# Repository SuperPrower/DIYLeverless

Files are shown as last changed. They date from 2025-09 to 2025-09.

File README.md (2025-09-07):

# SuperPrower's notes on DIY Leverless controllers

This repository contains my notes, pictures, and CAD files of the leverless controllers I have built or attempted to build.

Rather than being a blueprint for a projects, it should be used as a reference, inspiration or a list of mistakes to avoid. DIY mindset required.

Notes range from my philosophy when approaching something to my experience and advice based on it.

Repository structure:
- `flatbox`: contains the notes on my first controller, based on the [flatbox](https://github.com/jfedor2/flatbox) rev4 - TBA.
- `woodbox`: my most recent controller, built out of generic wooden box for storage.

The "Homework" sections contain mistakes I've made and things I would do differently in the future. If one is present, please read it if you're trying to replicate or be inspired by some of the ideas.

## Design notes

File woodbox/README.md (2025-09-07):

# Matchstick Box (aka Woodbox)

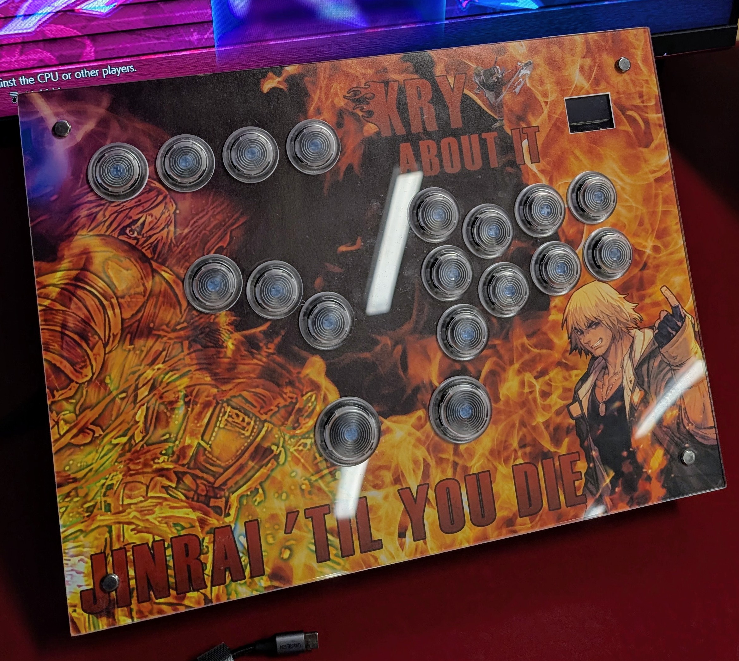
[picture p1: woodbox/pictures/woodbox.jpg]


The goal of the project was to make a controller that would be more comfortable for people with wider shoulders through split layout (movement buttons and attack buttons separated). Additionally, it was supposed to prevent Ulnar Deviation / wrist angling by slightly tilting each button block inwards. Bigger size also helps with more comfort when placed on the knees, which is something I would typically have to do at locals.

The initial sketches for button layouts were fitting roughly on the A4 sheet of paper. As such, I opted to purchase a hobby wooden box that could fit an A4 sheet inside.

I used a laser cutter at my local hackspace to cut the lid of the box and a sheet of acrylic to go on top of it.

## Files in this directory
Notes:
- [DESIGN.md](DESIGN.md) - notes on design of the controller
- [MAKING.md](MAKING.md) - notes on actually building the controller
- [WIRING.md](WIRING.md) - notes on installing the buttons and wiring them

Other files:
- [ButtonLayout.FCStd](ButtonLayout.FCStd) - the layout of the buttons and cutting layout for the case and acrylic plate, see [DESIGN.md](DESIGN.md) for notes.
- [USBPortMountPlate.FCStd](USBPortMountPlate.FCStd) - extra detail to help mount the USB port extender to the case, see [DESIGN.md](DESIGN.md) for notes.

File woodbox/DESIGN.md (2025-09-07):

# Design Notes

## Button layout
I'm not sure why the layout where movement and attack buttons are close together is so popular. I guess HitBox really wants to show you all the cool things you can do by pressing one movement button and one attack button with the same hand. However, in practice, I've never personally seen anyone actually do that.

I've started my design by basing it on some of the artwork layouts available for controllers. I had to adjust the spacing between the buttons to accommodate for the lip. In the end, I have probably overcompensated, but it works for me - you could probably go with smaller spacing.

Afterwards, I added the additional buttons, moved the button blocks further away from each other and rotated them inwards.

The button I've used have tabs on sides, and were intended to be used with a panel thinner, than the combined width of the plywood top and acrylic sheet. That's why I've added small cutouts to the sides of the holes when cutting plywood. I've been inspired by this [reddit post](https://old.reddit.com/r/fightsticks/comments/1auxf83/custom_leverless_controller_panel_design/).

Here is how one of the final iterations of the layout looked like (prepared for manual drilling, before I decided to use a laser cutter):

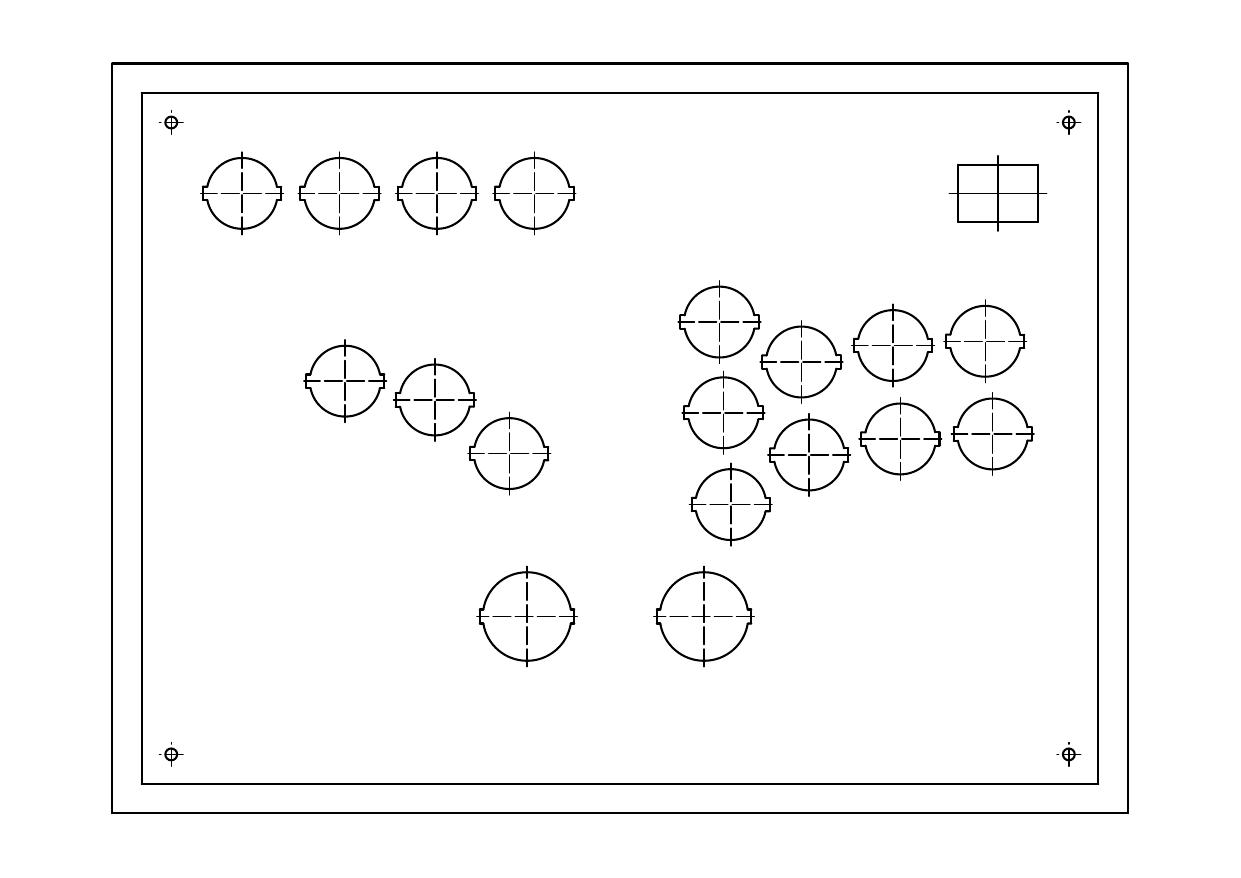
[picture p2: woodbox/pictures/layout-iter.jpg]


### Homework
- The layout I based mine on has LK and LP buttons (in SF6 notation) almost perfectly one on top of another. I found that not as nice, because I like to press those two buttons together with my index and middle fingers. I would re-design the layout based on the flatbox, which has the bottom row shifted slightly to the left, maybe even moving it more to the left slightly.
- I believe I overdid the split between the button blocks. I would go with a gap maybe 5 mm smaller.
- I rotated each button block inwards by 12.5 degrees around the larger 30mm buttons. However, I think it is very slightly too much. Next time I would go with ~10 degrees, especially when coupled together with the previous two changes.
- I'm not very familiar with the CAD software and FreeCAD in general. As such, after making the initial layout as a sketch, I made a copy of it and rotated each button block separately, losing most of my constraints and having to re-do them manually. Please find a better way to do that.
- Similarly, I've added the notches for buttons as rectangles and then merged them in the Laser Cutter software. Trying to merge them in the FreeCAD just caused me to lose constraints, which I didn't want.

## USB mount plate
The box I've purchased didn't have enough height in the wall to mount a Neutrik-style USB port. As such, I've opted to purchase a flatter USB Type C panel mounted extender. However, I didn't realize that you are intended to screw a thin plate on top of it, not screw it to something behind it. As such, I quickly designed a plate with 2 screw holes to mount the USB extender to it, 2 screw holes to mount it to the box, and a hole for the USB cable.

Unfortunately, I placed the holes through which the plate would be mounted to the case too close to the other holes. Because I was adding furniture threaded inserts to the case (think typical brass threaded insert, but for wood), they ended up not having enough clearance and not being safely covered by the wood from all sides:

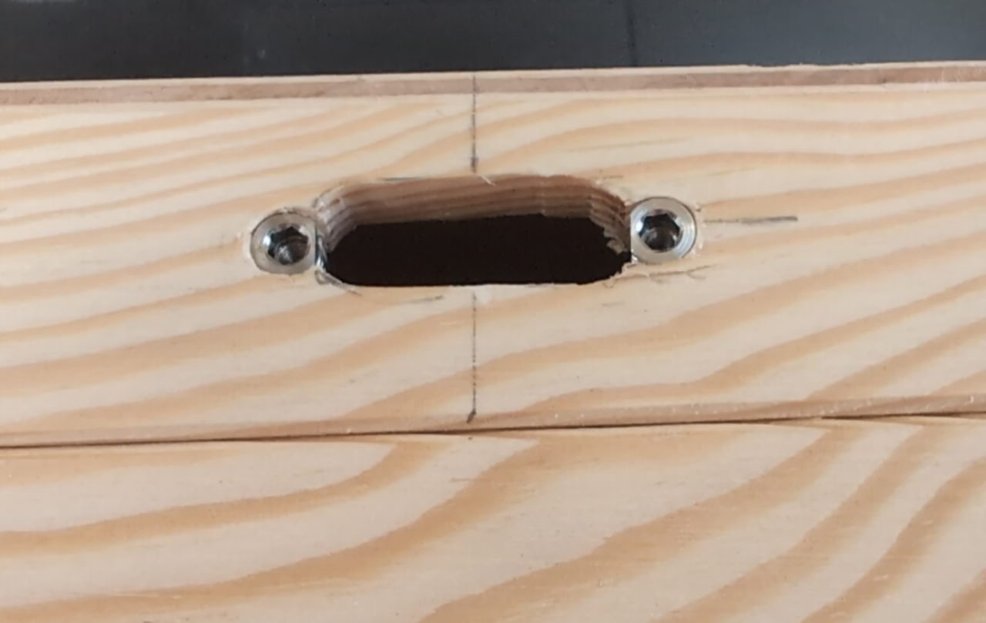
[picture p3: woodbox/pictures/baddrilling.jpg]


A lot of glue and wood filler eventually solved the problem, but I'm afraid to tighten the screws now. However, it works, and in theory I can disassemble the installation to replace the extender cable:

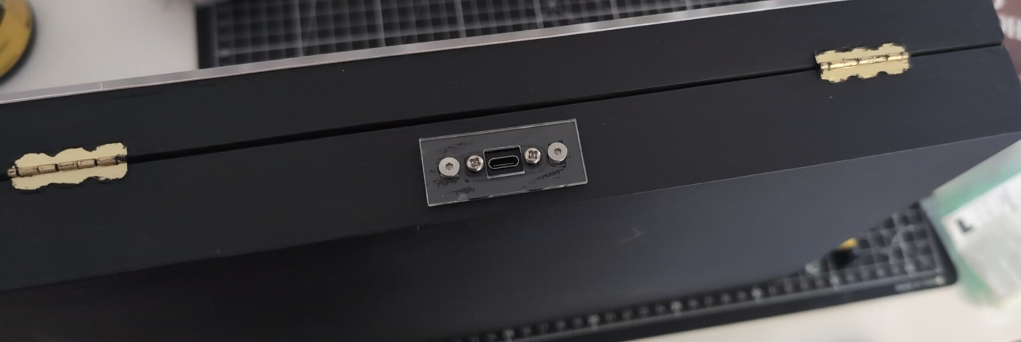
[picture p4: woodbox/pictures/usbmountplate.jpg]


### Homework
* Use a better USB extender - I believe Punk Workshop sells a similar one, but with screw holes being further out from the body of the USB port, or use a Neutrik-style panel mounted USB port.

## Display

I've added a small cutout to fit a small OLED. However, I didn't plan for mounting it - on the layout above, you seen that I only planned a hole for the display itself. Also, I had to manually sand out a small notch for the ribbon cable on the OLED. As such, it stays in place with friction between the edges of the display and the wood, and some tape.

### Homework
* Find a good way to mount a display. If the display is not touching the surface, I think it is possible to hide the bottom part of the glass that doesn't show anything, removing the need for a cable notch altogether.

## Artwork
I have exported the laser cutter layout for the acrylic sheet as svg and used it to design an artwork around it. I'm not sharing the art to avoid violating copyright, but I've used CC images of fire, various filters and layer blending modes in GIMP editor, and the following images:

- https://www.pixiv.net/en/artworks/101323675
- https://x.com/click_burgundy/status/1570615560433729536

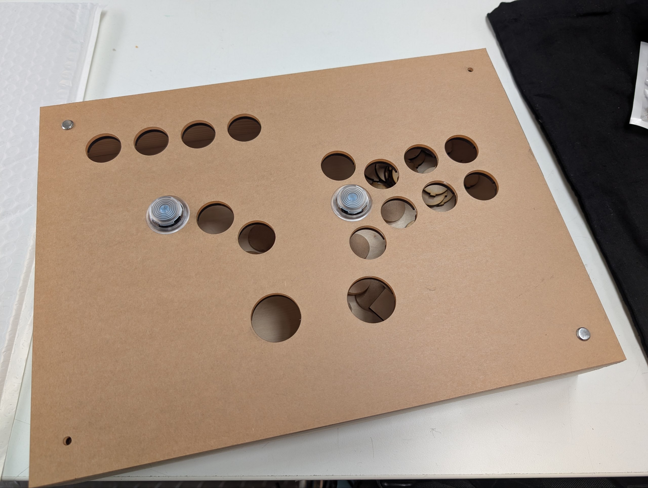
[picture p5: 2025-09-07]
woodbox/pictures/lasercut2.jpg

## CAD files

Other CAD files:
woodbox/ButtonLayout.FCStd
woodbox/USBPortMountPlate.FCStd

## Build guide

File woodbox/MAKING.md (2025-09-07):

# Notes on building the controller

## Making the holes for the buttons
I was initially planning to use a drill to make holes in the top lid of the box, but kind people at the hackspace suggested trying to use a laser cutter. The lid of the box is made out of thin plywood - 3-4mm thick - and the lid itself was short enough to fit under the moving head of the laser cutter.

I was very pleased with how it turned out. I plan to design my future controller around the laser cutter.

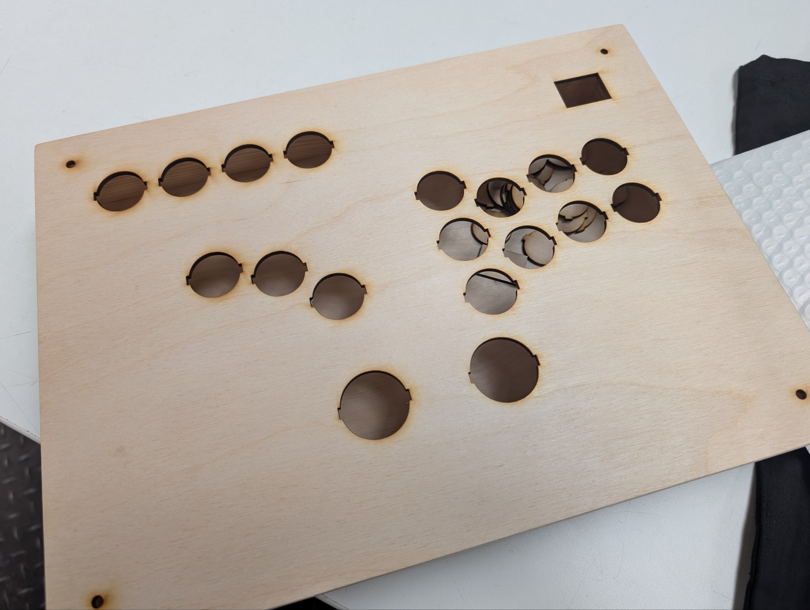
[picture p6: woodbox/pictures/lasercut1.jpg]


### Homework
- None! Laser cutter rules.

## Making the hole for the USB extender

For the USB extender, I drilled a round hole of the diameter matching the height of the USB extender, and then widened it using a Dremel-like tool and files. I don't recommend that approach, as the hole was uneven, I had to file it, fill it with the wood filler, and sand it, and after painting I had to slightly sand the casing of the USB extender.

To mount the USB Extender, I had to use a mounting plate - see DESIGN.md for explanation. As I wrote there, I miscalculated the width of the threaded inserts, and ended up with suboptimal mounting.

### Homework
- Find a better approach to making a non-round hole
- Plan for more space for the threaded inserts.

## Painting

My painting experience is limited by painting small plastic dudes. As such, I didn't know where to start with painting a box made out of pine and plywood. A WikiHow article suggested using a shellac-based primer, but I couldn't really find one in my closest hardware store. I also tried using some advice from an LLM, but in retrospect it was clearly making shit up based on the techniques used for painting small plastic dudes or painting outdoor furniture. I ended up buying a can of 2-in-1 acrylic paint & primer, rated for outdoor and indoor use, supposedly also fitting for use with the toys. I think that was an OK decision, though I was later criticized for painting a relatively small DIY project "like a wood fence".

First layers looked very promising:

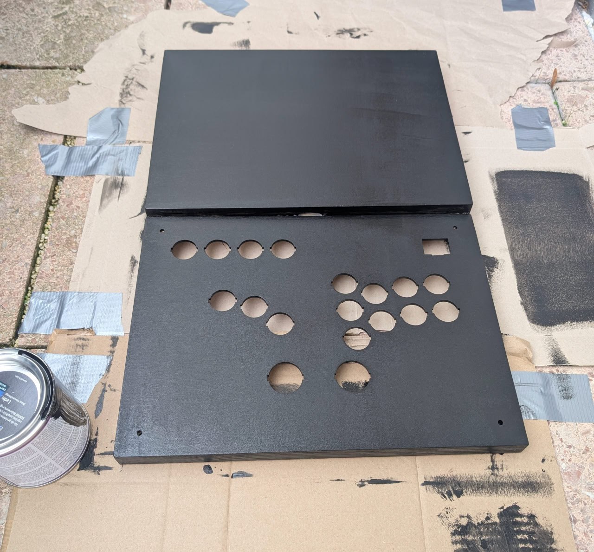
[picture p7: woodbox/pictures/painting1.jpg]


However, as I went on, it was clear that I was doing something wrong. Not only having to wait for ~24 hours between painting sessions seemed excessive, especially given that I had to paint my box inside and outside and on the sides, but soon enough paint started to look much worse:

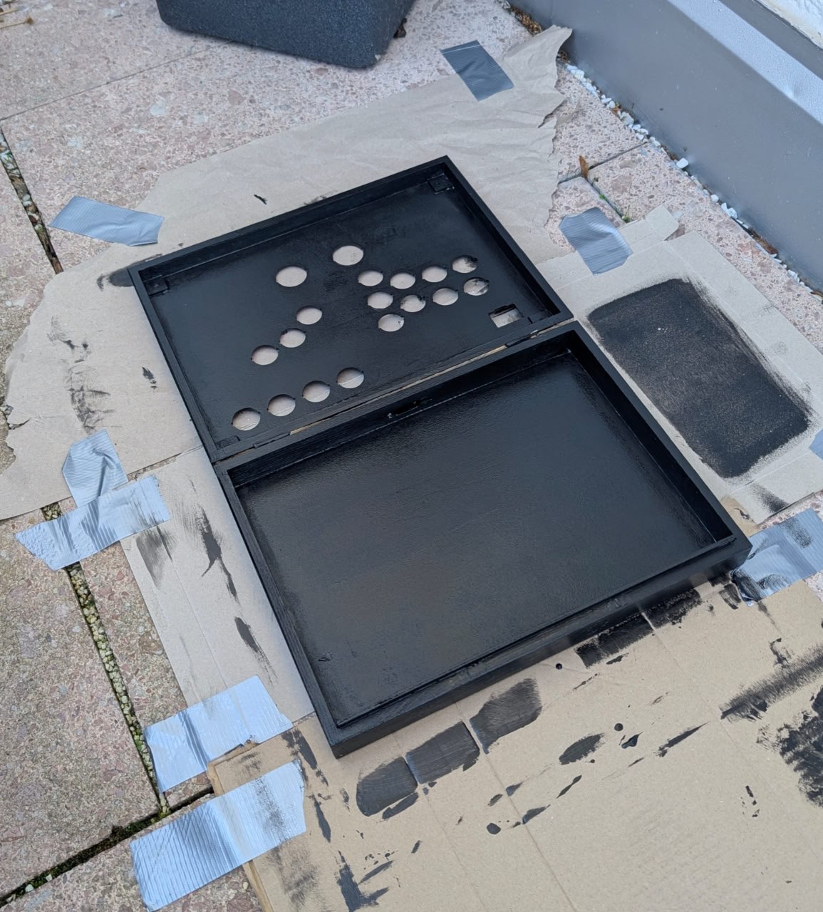
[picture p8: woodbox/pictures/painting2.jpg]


It was at that point that I realized that not only did I not stir my paint, but also that I was probably using a roller incorrectly. Oh well - after approximately two coats from each side and then some after sanding down blobs of paint, I had to call it "good enough".

Thankfully, after applying a clear coat from a spray can, the texture and appearance actually improved quite a bit. I really like the satin look of the clear coat, and would go for it again:

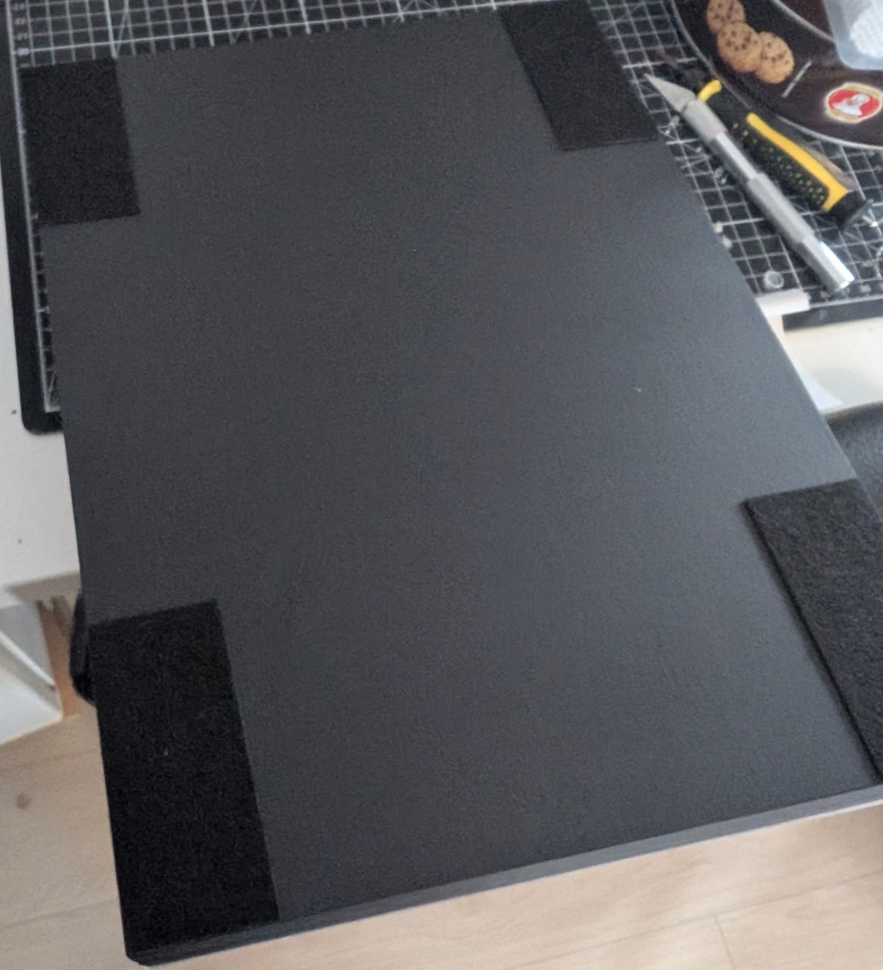
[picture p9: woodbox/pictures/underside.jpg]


### Homework
- When using a wooden box for case, some better painting approach should be used. Either just spraying it with the paint instead of using more generic outside paint, or some other painting approach.
- Don't forget to stir your paint first!
- The paint was so thick, that it completely glued the masking tape that I have applied to various metal parts to the box. It didn't help that because I had to open the box to paint the larger surfaces and close it to paint the sides, the masking tape didn't work as well in some places, like hinges - you can still see some paint on them, even though I did my best to scrape it or rub it off with isopropyl alcohol. In general, aim for a better masking job.

## Miscellaneous stuff

I also added some furniture gliders made from felt (see the picture above). Normally people add non-slip rubber feet to their controllers, but I haven't felt the need to - I just wanted to protect my controller from the surfaces (or vice versa), and make it a bit more comfortable to play with when wearing shorter clothing. I think it worked well enough.

The artwork was printed at the copy shop. Next time, I would go for a glossier and thicker paper to make it easier to cut holes for buttons.

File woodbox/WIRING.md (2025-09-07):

# Notes on wiring the controller

## Buttons

I've purchased a set of Punk Workshop buttons on AliExpress. I quite enjoyed having keyboard switches in my flatbox, and as such, chose the buttons which used them. The listing seems to be gone from the reseller, but they are listed as "PWS v1" on Punk Workshop webstore - albeit with button caps seemingly being deeper in the button case.

These buttons use 2.8mm terminals. I've bought a set of male and female 2.8mm terminals with covers for wiring, but I didn't enjoy using them - they are very hard to insert and remove - I would look for something more akin to what is used in the Brook harness.

## LEDs

When I received my buttons, I've noticed that the switches inside of them (Cherry MX Blue) had a small place for an LED in them. Turns out that those switches perfectly fit a 3mm LED. The button housing didn't have any holes for the diode legs, but if I bent the legs at the bottom of the switch, I could have them sticking out from the side of the button:

TODO picture of switch and LED

TODO picture of button with LED legs visible

As such, I made a decision to add an LED to the buttons. GP2040-CE has its own support for addressable LEDs, but it would be difficult to fit one into the switch, so I decided to make them activate on the button press.

I have found that GP2040-CE configures its buttons such that when pressed, they pull the pin down to the ground. With that knowledge, I was able to connect the anode of the LED to the VCC pin, and the cathode to the GPIO pin. This way, when the button is pressed, the circuit will close, and an LED will light up, but if LED dies, the button won't stop working.

TODO schematic of LED

### Small note on LEDs
The Cherry MX switches (non-RGB version) fit 3mm LEDs, however I've discovered that depending on the color, some LEDs' skirts needed to be slightly sanded down to fit into the switch, while others fit perfectly or even slightly loose. Your mileage may vary, but in my experience, yellow and red LEDs fit snugly, green LEDs are a bit loose, and blue and white LEDs needed to be sanded down. Other switches may expect different size of LEDs, for example 1.8mm.

### Homework
- I wanted to make it so I don't need to de-solder anything to remove the button. To achieve that, I've soldered 2.8mm terminals, same ones used by the buttons, to the legs of LEDs. I've also soldered a resistor to the LED instead of to the cable going to it. However, this proved to be a bad decision, because all of it takes too much space and looks really messy at the end:
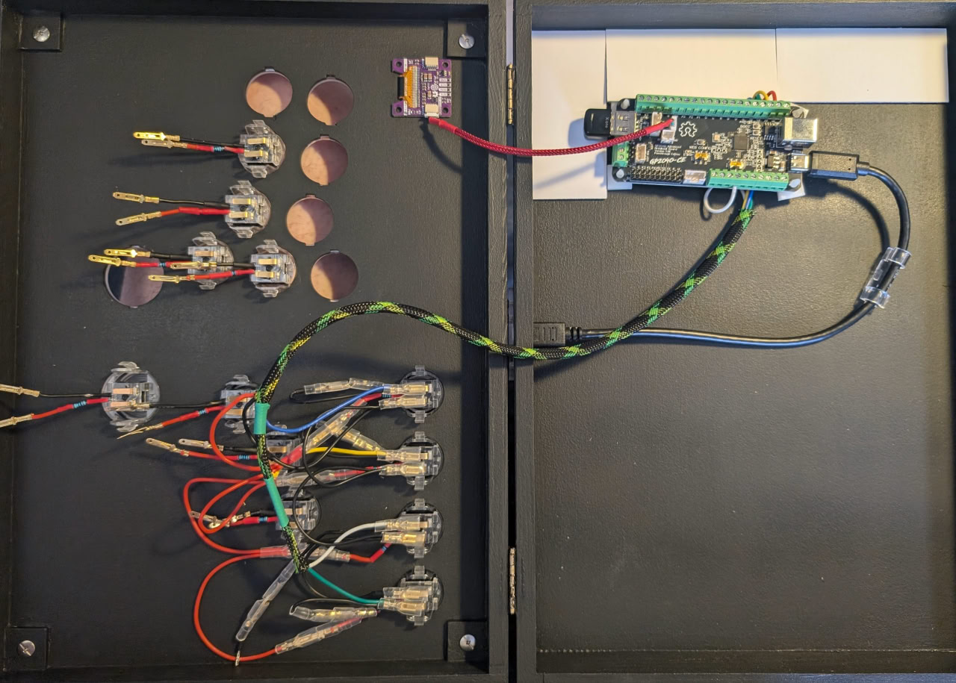
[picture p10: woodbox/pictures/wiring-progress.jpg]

- Next time, I would probably look for some sort of connection which would fit the legs of LEDs and hold them firmly, similar to how hot swap sockets for keyboard switches work.
- Either because the VCC pin on the board is 5V and the logic pins are pulled up to 3.3V or for some other reason, some LEDs, namely reds and to a lesser extent yellows, can be faintly seen glowing when not pressed. That's probably not great for their longevity.

## Component placement

I've made a decision to have the GP2040 board at the bottom part of my case, with cables going to the top part. This was done partly because the pre-crimped JST SH 1.0mm (a.k.a. QWIIC) cables I had that I used to connect an OLED were really short, and because the USB extender was mounted in the bottom part. That worked out in the end, but next time I would try to have all of the components mounted on the same surface.

Also, I didn't plan a proper mounting for OLED. I couldn't use the same stands that the board uses, since they would cover the screen. For now, it stays put with friction and some tape.

### Homework
- Plan for the board to be on the same surface with the buttons.
- Plan better mounting for the OLED.

## Wiring

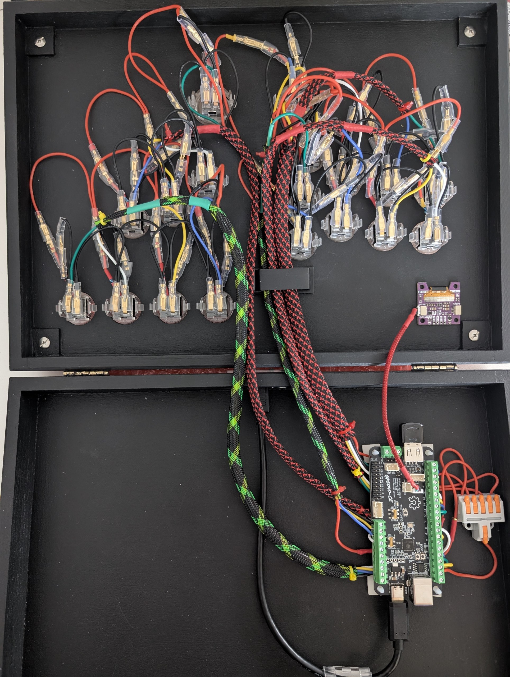
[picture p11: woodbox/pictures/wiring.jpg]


Although I've bought a pre-made cable harness for leverless controllers, I didn't want to use it since the pin grouping wasn't working for me, and I was worried that the 20 pin connector would make the board too tall. I ended up making my own cable harnesses, intended to be connected to the screw terminals on the GP2040 board.

TODO picture of harness

I've used 22 AWG wires. I think they are a bit on the thicker side, especially when compared to the typical wiring job, but I think they worked well with the 2.8mm terminals that I've used, though I couldn't fit 2 cables together inside the terminal for crimping without fully removing the isolation. Next time, I would probably go with something slightly smaller, but definitely thicker than 30 AWG.

### Notes on sleeving
I wanted to sleeve my cables for cleaner (and cooler) look. For that, I bought some various cable sleeves.

For 22 AWG cables, I would say a cable sleeve with maximum internal diameter of 6mm can fit 4-5 wires comfortably, 6 if you're pushing it. I wired my buttons in groups of at most 4, so I needed 4 wires to each GPIO pin, 1 common Ground wire, and one common VCC cable. I used 6mm (green on pictures) and 12mm (red) sleeving. Next time, I would probably go with 8mm cable sleeving, unless I would go for thinner wires.

It is possible to cut the sleeving and make holes in it to let some cables out earlier, but you need to treat the cut with head to seal it up and prevent it from unraveling. I used a lighter, but flames were probably too wide to make it a clean job. I would suggest you look for a dedicated cutter tool at your local workshop for a cleaner cuts.

There are various methods of routing your cable through sleeving, but I found it very easy to just stretch the sleeving over a metal drinking straw, feed the cables through it, and then slowly pull the sleeving out alongside the cables.

### Homework
- Some of the cables I made were a bit too short and had to stretch out, some of them were a bit too long. Next time, I would plan better for the cable placement together with the component placement and try to go for neater cables. Same goes for sleeving.
- For my LED cable terminals, I have added a silicon sleeve that came with the terminals to both sides of the cable. I now think that this may have been excessive - similar to the terminals on the buttons, you probably could only use one cover on one side.
- I tied the ends of the sleeves with small colorful zip ties. I would get some more colors next time for easier identification of sleeves, and maybe also add some heat shrink tubing at the ends of the cut to seal it up even further.
- It was later that I have found a guide for wiring fighting game controllers. [Link to the guide](https://drive.google.com/file/d/1Ho5ItRj8jMYTG4tVbq0kyc-aFqbbF-iD/view?usp=sharing). There were some interesting techniques there, like reverse-crimping of 2.8mm terminals on wires, as well as an advice to not cut the sleeves to pull out cables, rather just pushing the strands of the sleeve aside for a cleaner job.
